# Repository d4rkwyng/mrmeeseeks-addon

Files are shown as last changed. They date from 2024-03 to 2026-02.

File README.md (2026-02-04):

# Mr MeeSeeks Shitty Addon

A #badgelife shitty addon PCB designed for DEF CON 26.

Created by @d4rkwyng and SparX. Thanks to [AND!XOR](https://www.andnxor.com/) for their instructional video on the schematics used in this project.

## Preview

| Front | Back |
|:-:|:-:|
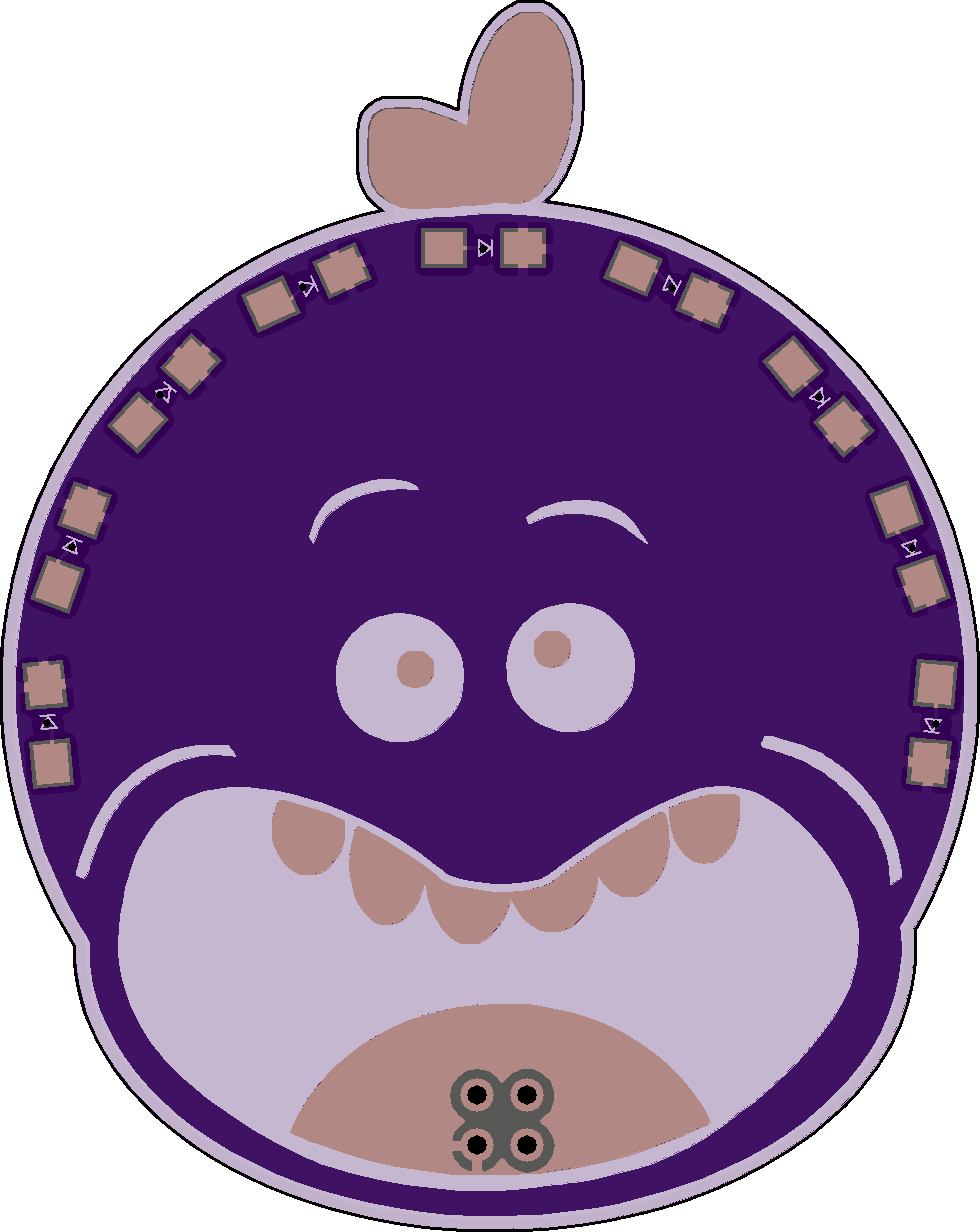
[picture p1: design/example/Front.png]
Front
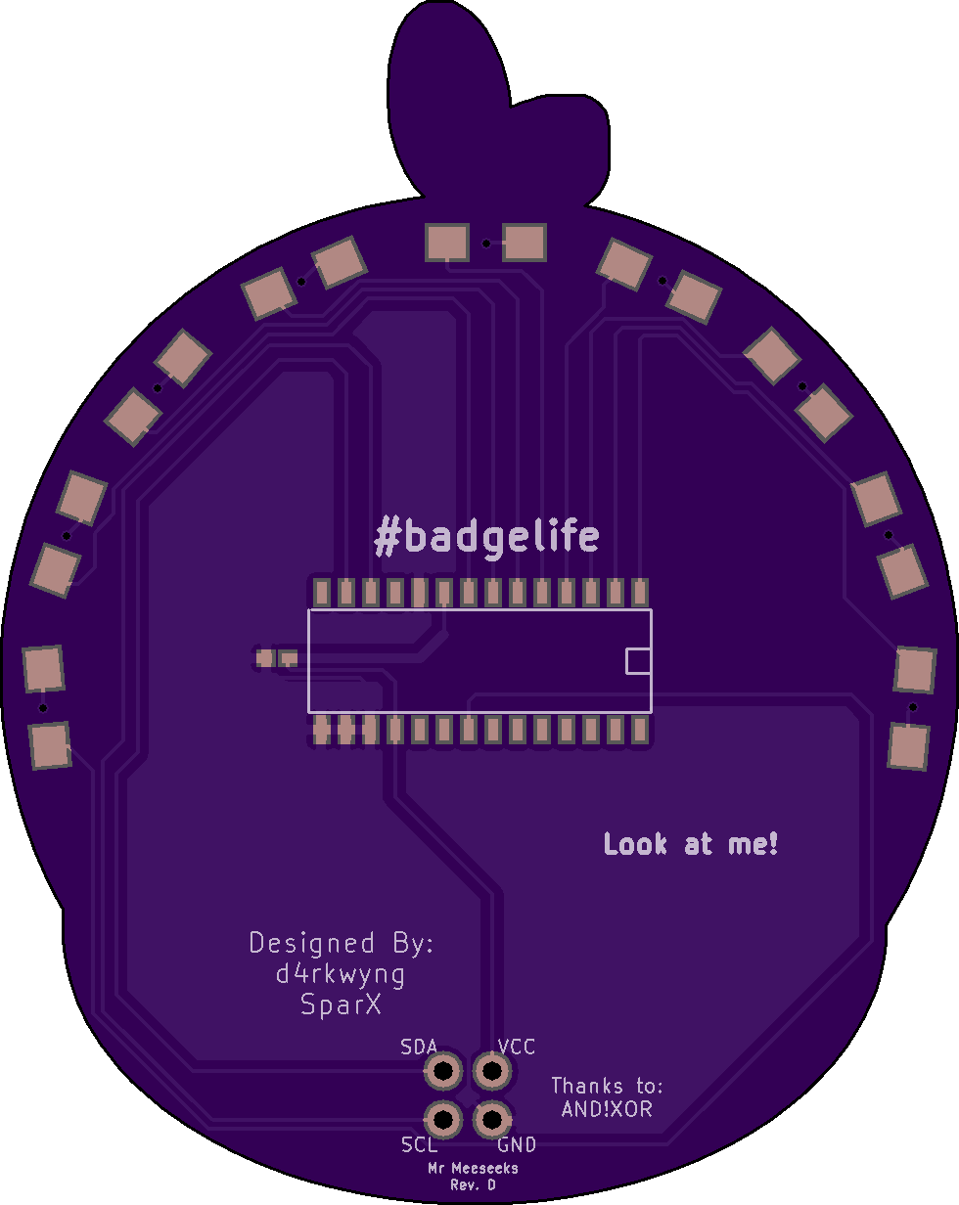
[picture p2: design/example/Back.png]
Back
|  |  |

## Bill of Materials

| Ref | Component | Package | Qty |
|-----|---|---|-----|
| U1 | MCP23017 | SOIC28 | 1 |
| D1-D8 | LED | 1206 | 8 |
| R1-R8 | 220 ohm | 1206 | 8 |
| C1 | 0.1uF | 1206 | 1 |
| X1 | Shitty connector | 2x2 | 1 |

## Revisions

- **Rev E** — Final revision with ESO/SSO variants
- **Rev D** — Updated layout
- **Rev C** — Routing improvements
- **Rev B** — Component changes
- **Rev A** — Initial prototype

## Project Structure

```
mrmeeseeks-addon/
├── design/          # Artwork, silkscreen, and soldermask KiCad footprints
├── gerbers/         # Manufacturing files (Rev D & E)
├── lib/             # KiCad component libraries
└── mrmeeseeks_*     # Schematic, PCB, and netlist files
```

## Tools

- [KiCad](https://www.kicad.org/) — Schematic and PCB design

## License

MIT License. See [LICENSE](LICENSE) file.

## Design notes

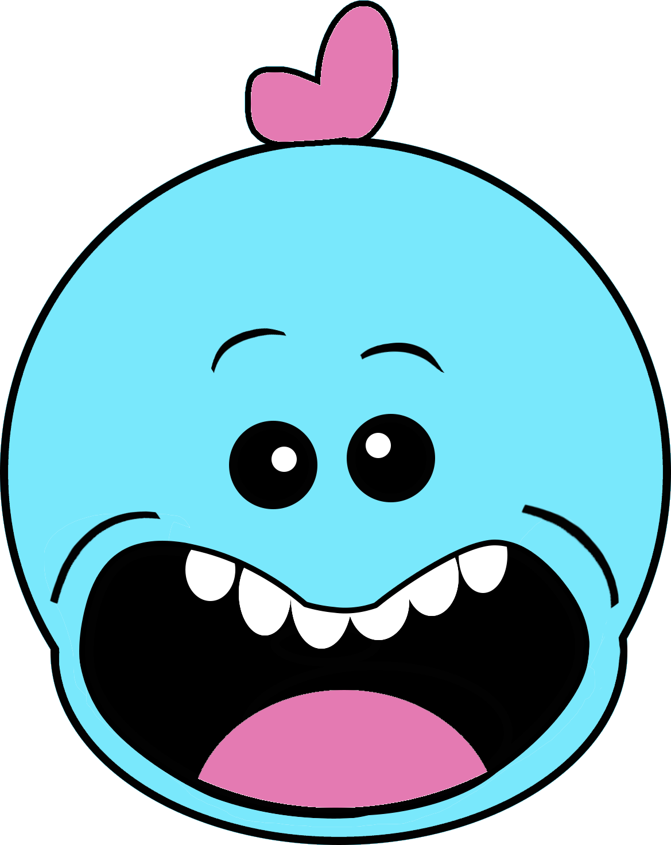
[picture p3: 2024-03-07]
design/mrmeeseeks-concept.png

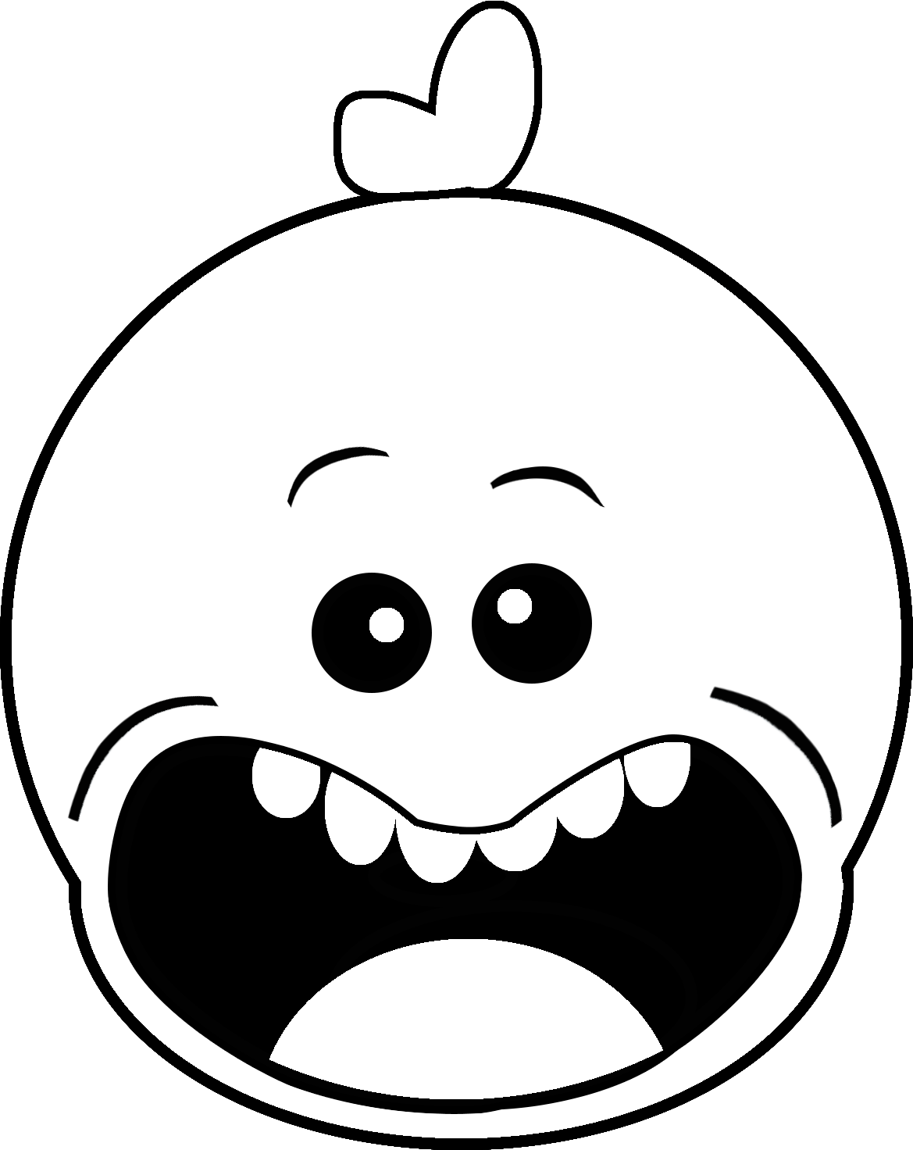
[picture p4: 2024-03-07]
design/mrmeeseeks-silkscreen.png

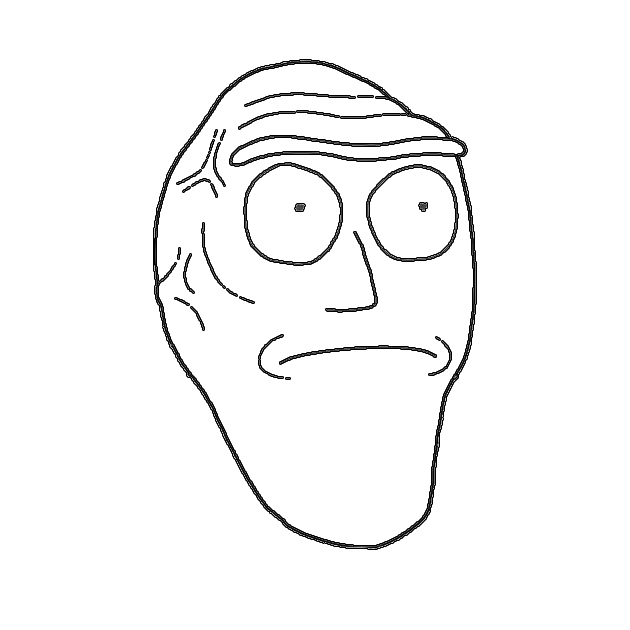
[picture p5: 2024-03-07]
design/smwyg.png

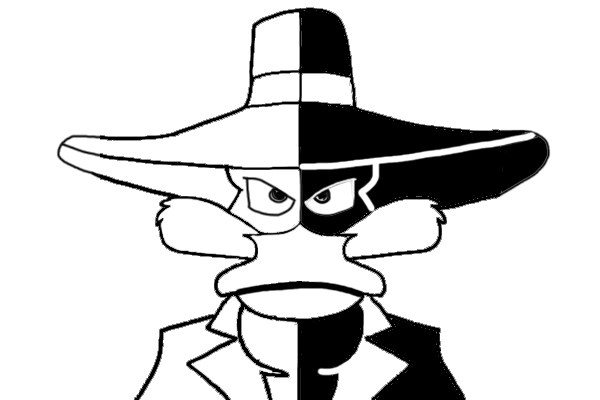
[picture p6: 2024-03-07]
design/d4rkwyng.png

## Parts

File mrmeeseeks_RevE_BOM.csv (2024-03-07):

Id | Designator | Package | Quantity | Designation | Supplier and ref
1 | G*** | soldermask | 1 | LOGO
2 | G*** | silkscreen | 1 | LOGO
3 | X1 | Badgelife-Shitty-2x2 | 1 | Badgelife_shitty_connector
4 | R6,R1,R2,R3,R4,R5,R7,R8 | R_1206_HandSoldering_NoSilk | 8 | 220
5 | D1,D2,D3,D4,D5,D6,D7,D8 | LED_1206_HandSoldering_MinSilk | 8 | LED
6 | U1 | SOIC28-1.27-17.9X7.5MM | 1 | MCP23017
7 | C1 | C_1206_HandSoldering | 1 | 0.1uf

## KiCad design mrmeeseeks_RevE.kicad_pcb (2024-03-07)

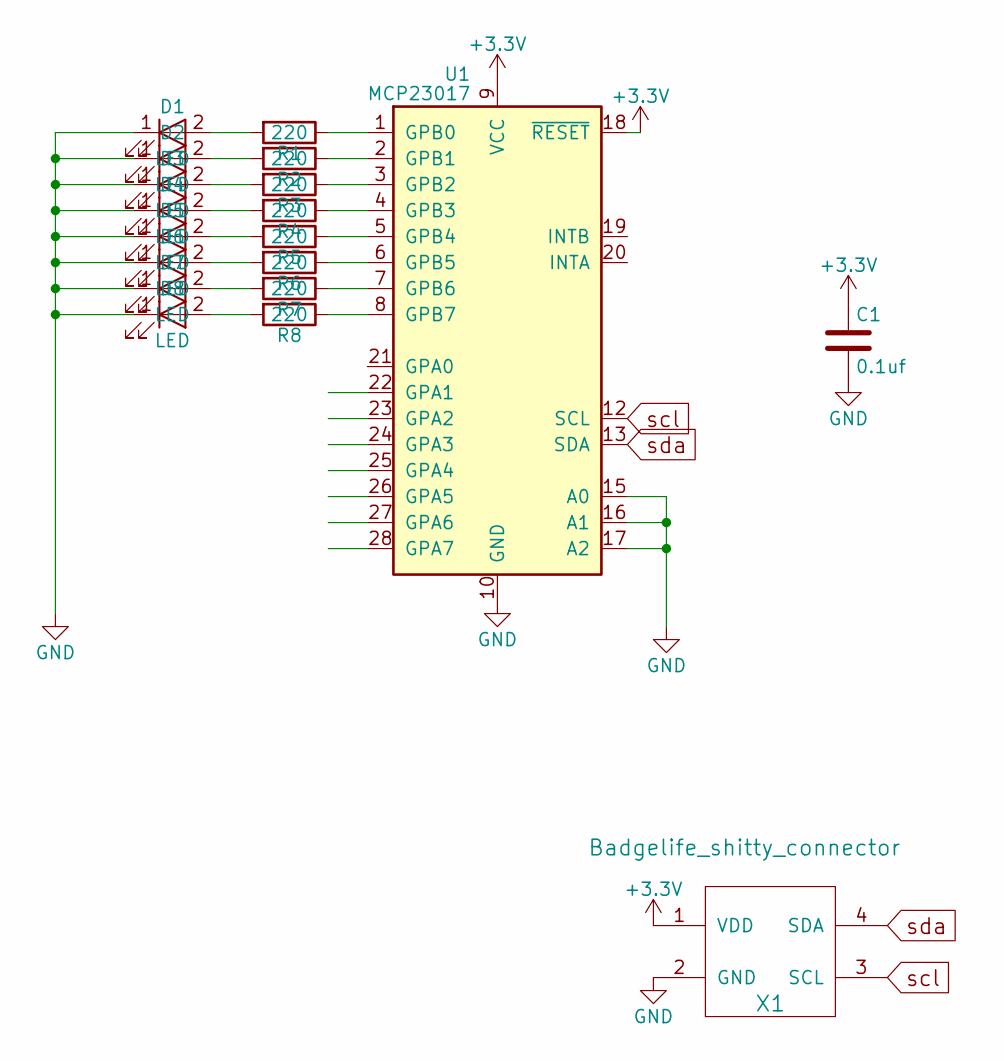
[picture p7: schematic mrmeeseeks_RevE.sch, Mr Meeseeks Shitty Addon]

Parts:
C1: 0.1uf; C_1206_HandSoldering
D1, D2, D3, D4, D5, D6, D7, D8: LED; LED_1206_HandSoldering
R1, R2, R3, R4, R5, R6, R7, R8: 220; R_1206_HandSoldering
U1: MCP23017; SOIC28-1.27-17.9X7.5MM
X1: Badgelife_shitty_connector; Badgelife-Shitty-2x2

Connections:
+3V3: C1.1, U1.9 (VCC), U1.18 (~RESET), X1.1 (VDD)
GND: C1.2, D1.1 (K), D2.1 (K), D3.1 (K), D4.1 (K), D5.1 (K), D6.1 (K), D7.1 (K), D8.1 (K), U1.10 (GND), U1.15 (A0), U1.16 (A1), U1.17 (A2), X1.2 (GND)
unnamed: D1.2 (A), R1.2
unnamed: D2.2 (A), R2.2
unnamed: D3.2 (A), R3.2
unnamed: D4.2 (A), R4.2
unnamed: D5.2 (A), R5.2
unnamed: D6.2 (A), R6.2
unnamed: D7.2 (A), R7.2
unnamed: D8.2 (A), R8.2
unnamed: R1.1, U1.1 (GPB0)
unnamed: R2.1, U1.2 (GPB1)
unnamed: R3.1, U1.3 (GPB2)
unnamed: R4.1, U1.4 (GPB3)
unnamed: R5.1, U1.5 (GPB4)
unnamed: R6.1, U1.6 (GPB5)
unnamed: R7.1, U1.7 (GPB6)
unnamed: R8.1, U1.8 (GPB7)
scl: U1.12 (SCL), X1.3 (SCL)
sda: U1.13 (SDA), X1.4 (SDA)

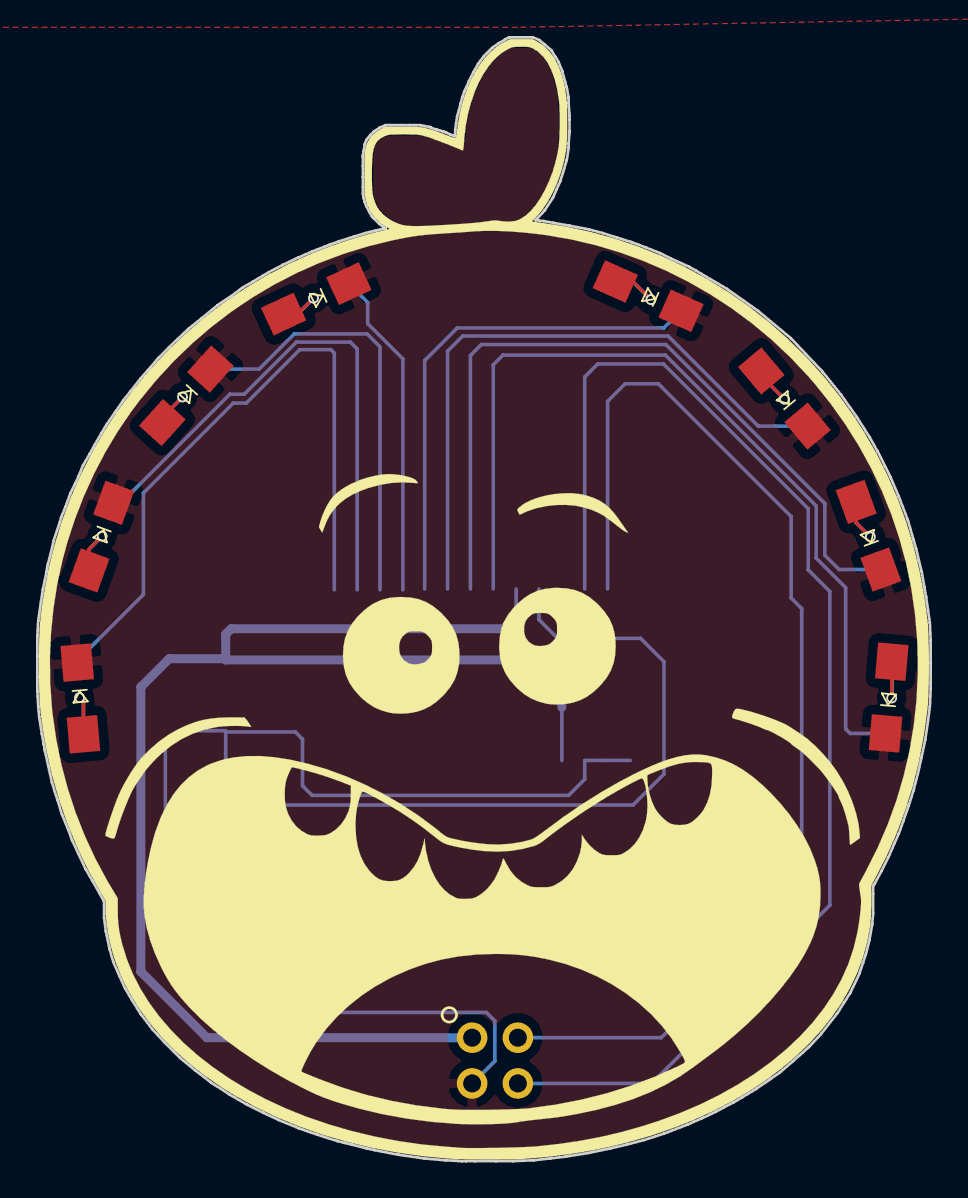
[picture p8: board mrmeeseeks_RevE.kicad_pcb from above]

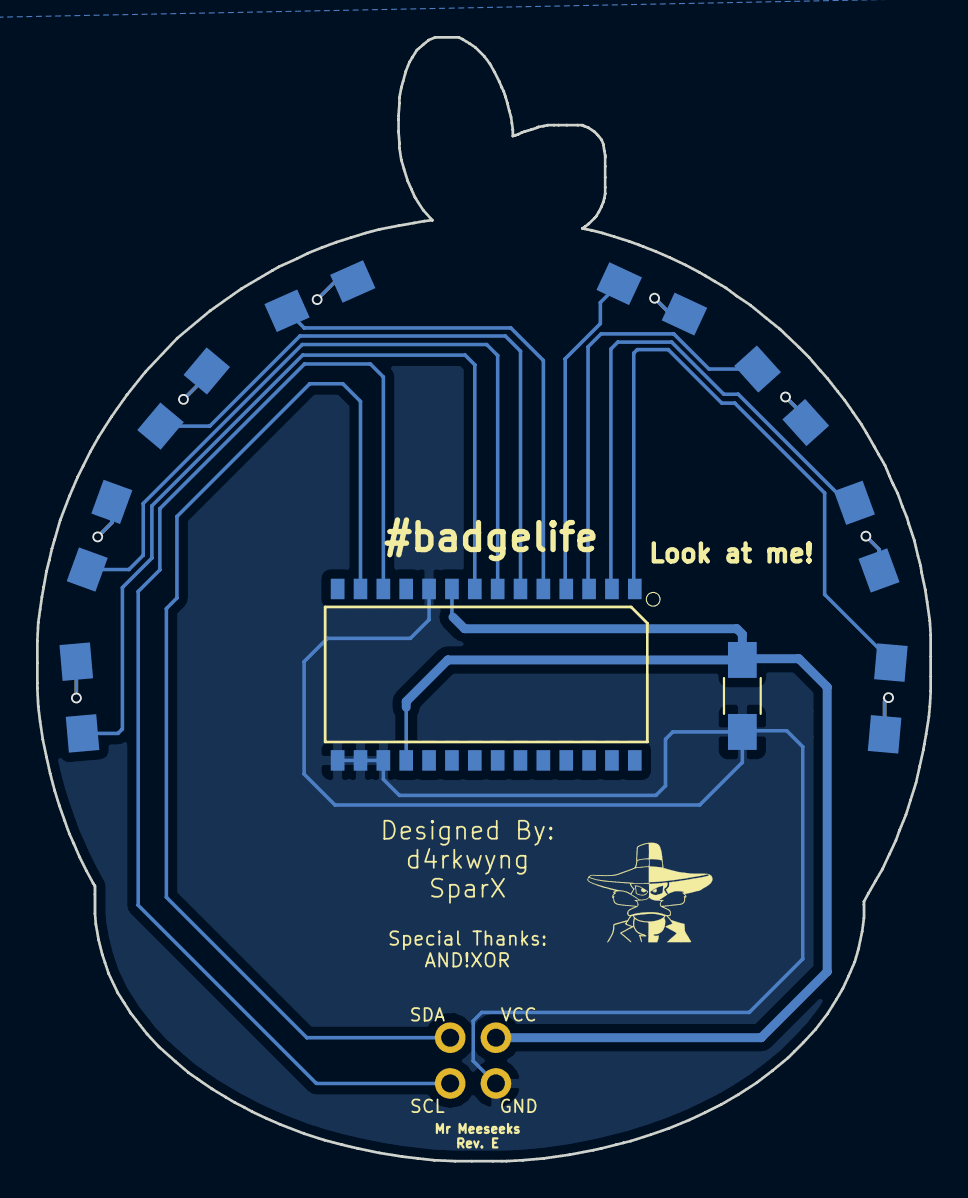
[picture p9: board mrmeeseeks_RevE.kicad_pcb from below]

Board: 2 copper layers, 49.6 x 62.4 mm, 19 parts (10 on the bottom side), 20 nets.

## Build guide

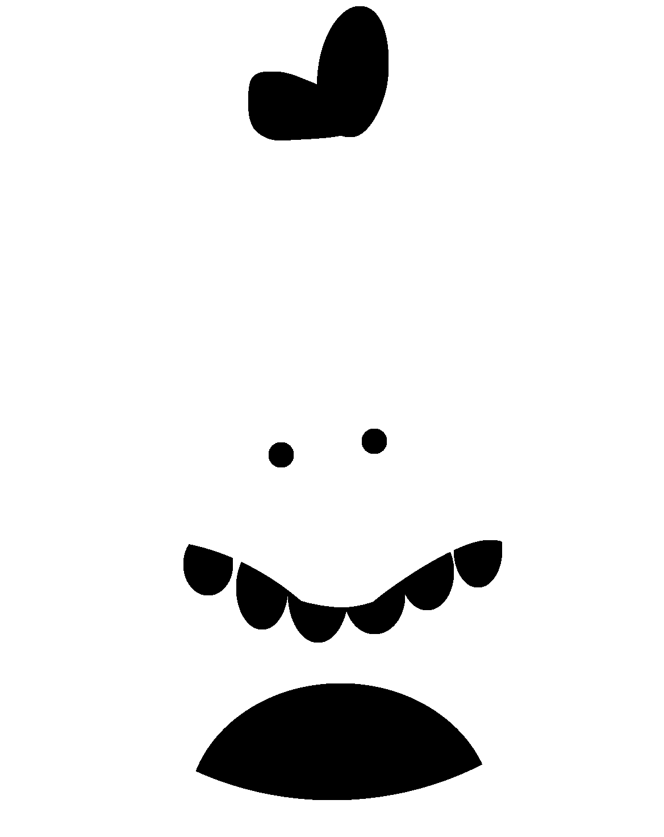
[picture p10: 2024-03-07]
design/mrmeeseeks-soldermask.png

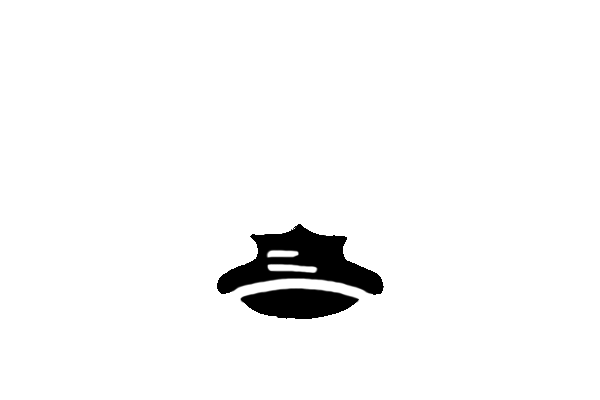
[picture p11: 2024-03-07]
design/d4rkwyng_solder.png

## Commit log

2024-03-07 MrMeeseek Images
    [mrmeeseeks.kicad_pcb, mrmeeseeks.sch]
2024-03-07 Image Update
    [mrmeeseeks.kicad_pcb, mrmeeseeks.sch]
2024-03-07 Schematic Complete
    [mrmeeseeks.sch]
2024-03-07 Edge Cuts to PCB
    [mrmeeseeks.kicad_pcb]
2024-03-07 Updated PCB Design
    [mrmeeseeks.kicad_pcb, mrmeeseeks.sch]
2024-03-07 Draft 1 of PCB Done
    All tracers added
    [mrmeeseeks.kicad_pcb]
2024-03-07 Gerbers Added
    [mrmeeseeks-B.Cu.gbl, mrmeeseeks-B.Mask.gbs, mrmeeseeks-B.Paste.gbp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]
2024-03-07 Design By Updates
    [mrmeeseeks.kicad_pcb]
2024-03-07 Removed Totem
    [Totem.GBL, Totem.GBO, Totem.GBP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]
2024-03-07 Updates to Soldermask Layer
    [mrmeeseeks-B.Cu.gbl, mrmeeseeks-B.Mask.gbs, mrmeeseeks-B.Paste.gbp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]
2024-03-07 Draft 2
    Redesigned tracers
    [mrmeeseeks-B.Cu.gbl, mrmeeseeks-B.Mask.gbs, mrmeeseeks-B.Paste.gbp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]
2024-03-07 Updated Traces
    [mrmeeseeks-B.Cu.gbl, mrmeeseeks-B.Mask.gbs, mrmeeseeks-B.Paste.gbp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]
2024-03-07 Added traces to Front as Gerber2
    Backup is original PCB file.
    [mrmeeseeks-B.Cu.gbl, mrmeeseeks-B.Mask.gbs, mrmeeseeks-B.Paste.gbp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]
2024-03-07 No Trace PCB
    Classified as Original
2024-03-07 Revision D
    No holes on front for traces
    [mrmeeseeks_RevB.kicad_pcb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]
2024-03-07 Rev C committed
    [mrmeeseeks_RevC.kicad_pcb]
2024-03-07 Revision Tagging
    [mrmeeseeks.kicad_pcb, mrmeeseeks_RevB.kicad_pcb, mrmeeseeks_RevC.kicad_pcb]
2024-03-07 Clean Up
    [mrmeeseeks-B.Cu.gbl, mrmeeseeks-B.Mask.gbs, mrmeeseeks-B.Paste.gbp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]
2024-03-07 Rev D Updates
    [mrmeeseeks-B.Cu.gbl, mrmeeseeks-B.Mask.gbs, mrmeeseeks-B.Paste.gbp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]
2024-03-07 Revision E
    [mrmeeseeksRevE.sch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]
2024-03-07 Project Updates
    [mrmeeseeks_RevA.kicad_pcb, mrmeeseeks_RevA.sch, mrmeeseeks_RevE.sch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]
2024-03-07 Show Me What You've Got Update
    [mrmeeseeks_RevE-B.Cu.gbl, mrmeeseeks_RevE-B.Mask.gbs, mrmeeseeks_RevE-B.Paste.gbp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]
2024-03-07 The terror that flaps in the night!
    [mrmeeseeks_RevE-B.Cu.gbl, mrmeeseeks_RevE-B.Mask.gbs, mrmeeseeks_RevE-B.Paste.gbp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]
2024-03-07 Minor Library Changes
    [mrmeeseeks_RevE.kicad_pcb]
2024-03-07 Rev E ESO Version
    [mrmeeseeks_RevE_ESO-B.Cu.gbl, mrmeeseeks_RevE_ESO-B.Mask.gbs, mrmeeseeks_RevE_ESO-B.Paste.gbp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]
2024-03-07 ESO Gerber
2024-03-07 Revert "ESO Gerber"
    This reverts commit d02b66e383884bd23c169393c7deaf4388623bbe.
2026-02-04 Clean up repo: add gitignore, license, and improve README
    - Add .gitignore for KiCad backup files and OS junk
    - Add MIT license
    - Rewrite README with BOM table, revision history, and project structure
    - Remove tracked backup files (.bak, .kicad_pcb-bak)
2026-09-10 Fix broken library refs in RevE schematic and fp-lib-table
    mrmeeseeks_RevE.sch declared its cache lib as LIBS:mrmeeseeksRevE-cache
    (no underscore) but the file on disk is mrmeeseeks_RevE-cache.lib (with
    underscore) — a regression from the Rev E rename, since Rev A's
    LIBS:mrmeeseeks-cache line correctly matches its own file. U1 (MCP23017)
    is defined only in that cache lib, so this left it unresolved on a fresh
    open. Also drop the LIBS:INTERFACE-MCP23017-E_SOIC28_ line, a dangling
    reference to a footprint name (U1's F2 field) that was mistakenly also
    added as a symbol library — no such library file exists anywhere in the
    repo.
    Also add the missing mrmeeseeks-design footprint library nickn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
    [mrmeeseeks_RevE.sch]
2026-09-20 Finish footprint library cleanup left incomplete by d13783b
    d13783b fixed the RevE schematic's symbol-library ref but the
    footprint-library side of the same regression was still broken:
    fp-lib-table only declared mrmeeseeks-design, while every populated
    footprint on the RevE/RevE_ESO boards (U1, X1, R1-R8, D1-D8) actually
    uses the mrmeeseeks-addon, mrmeeseeks-addon-design or mrmeeseeks-lib
    nicknames, none of which had table entries. Confirmed with
    `kicad-cli pcb drc`: RevE dropped from 21 lib_footprint_issues to 1
    (the sole remainder, Capacitors_SMD, is KiCad's own stock library and
    out of repo scope); RevA-D pick up the mrmeeseeks-addon-design entry
    too.
    - fp-lib-table: add mrmeeseeks-addo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
    [mrmeeseeks_RevE.sch]
2026-10-15 Correct README Rev E variant/BOM details; ignore KiCad local files
    The README described Rev E as having "ESO/SSO variants" and listed U1 as
    SOIC28 only. Checked against the boards and gerbers: mrmeeseeks_RevE
    places MCP23017-ESO_NoSilk (SOIC-28, 1.27 mm pitch, B.Paste 0.762x1.143
    pads) while mrmeeseeks_RevE_ESO places MCP23017-ESS_NoSilk (SSOP-28,
    0.65 mm pitch, B.Paste 0.4318x1.651 pads) -- the opposite of what its
    filename suggests. The Rev B/C/D one-liners ("Component changes",
    "Routing improvements", "Updated layout") were not supported by the
    files (A-D share the same footprint set); replaced with what the repo
    actually contains. Also note that Rev A-D carry D9/R9 and an 0402 C1.
    .giti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
2026-10-18 Fix swapped INTA/INTB in SnapEDA MCP23017 symbol; document Rev E I2C/LED map
    lib/MCP23017-ESO.lib (SnapEDA INTERFACE-MCP23017-E(SOIC28)) had INTB on
    pin 20 and INTA on pin 19. Microchip DS20001952C Table 2-1 (SOIC/SPDIP/
    SSOP column) gives INTB = 19, INTA = 20. Swapped the pin numbers only;
    pin positions unchanged. No board impact: this symbol is not used by
    mrmeeseeks_RevE.sch (U1 comes from mrmeeseeks_RevE-cache.lib, which is
    already correct) and INTA/INTB are unconnected on both Rev E boards.
    README: add Rev E hardware notes derived from the schematic and checked
    against both Rev E PCB netlists -- I2C address 0x20 (A0-A2 to GND),
    LEDs on GPB0-7 active high, Port A/INT unconnected, RESET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
2026-10-23 Remove unused legacy MCP23017 .mod footprint libraries
    The fp-lib-table rows MCP23017-ESO and MCP23017-ESS (type Legacy, pointing
    at lib/MCP23017-ESO.mod and lib/MCP23017-ESS.mod) are used by no board:
    Rev E and Rev E ESO use mrmeeseeks-lib:MCP23017-ESO_NoSilk and
    mrmeeseeks-lib:MCP23017-ESS_NoSilk, and Rev A-D use Libraries:SOIC-28_NoSilk.
    Removed both files and both rows. kicad-cli 10.0.6 DRC on all six boards
    reports the same violations before and after.
    lib/MCP23017-ESO.lib is kept as the corrected reference symbol (ff0f8bb).
2026-10-29 Sync Rev E BOM with the board; document the unused GPA0 net
    mrmeeseeks_RevE_BOM.csv is a pcbnew export from 2018-06-13 (119e088). It
    was made before aacb9ba switched U1 from the SnapEDA footprint
    SOIC28-1.27-17.9X7.5MM to mrmeeseeks-lib:MCP23017-ESO_NoSilk, so it still
    named the old footprint. It also left out three art footprints that are on
    the current board (smwyg, d4rkwyng, d4rkwyng_solder). U1's pad positions
    are the same in the old and new footprints; only the name was stale.
    README: Rev A-D drive D9/R9 from GPA0. Both Rev E boards keep that net
    name on U1 pin 21, but nothing else is on the net and no copper uses it.
    Also note that the CSV covers the SOIC board; the SSOP board uses
    MC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
2026-11-06 Document Rev E gerber provenance and SSOP solder-mask web
    The SOIC Rev E gerbers (and RevE.zip) were plotted 2018-06-13, before
    aacb9ba moved U1's value text from B.SilkS to B.Fab, so the back silk
    gerber still carries that text. Copper, mask, paste, edges and drill are
    unaffected. Also record that the 0.2 mm pad-to-mask clearance leaves no
    mask web between U1 pins on the 0.65 mm-pitch SSOP board.
